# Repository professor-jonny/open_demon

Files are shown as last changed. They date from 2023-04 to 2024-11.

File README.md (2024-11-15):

# Open Demon Project
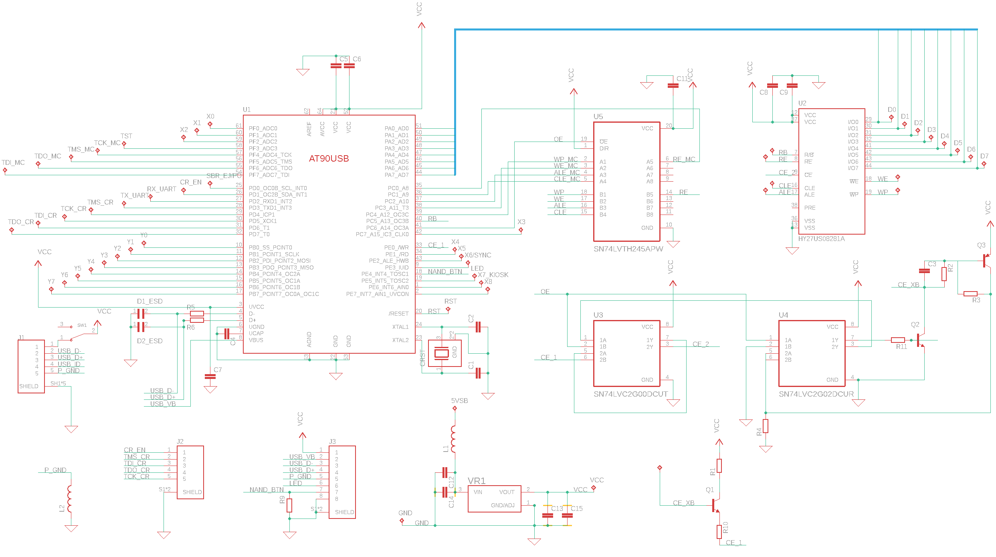
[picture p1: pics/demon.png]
sch

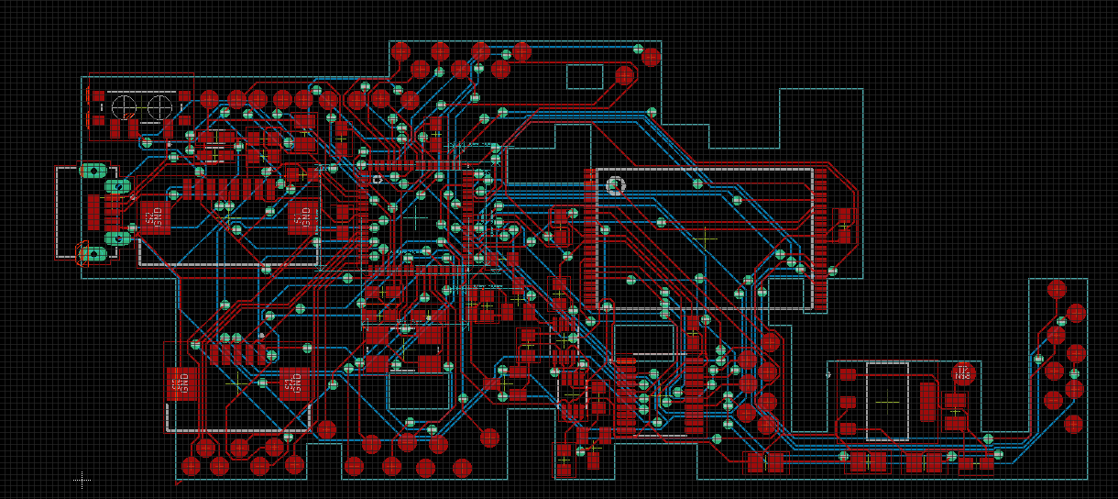
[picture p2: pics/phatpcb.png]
pcb


## Overview:
This project is an open-source recreation of the Team Xecuter Demon, a powerful multi-function NAND device for the Xbox 360. Our goal is to rebuild the firmware, fix existing bugs, and potentially develop new hardware add-ons. We hope this project encourages wider community involvement.

## Demon background:
Released in February 2012 alongside a J-Runner update, the Demon offered an all-in-one solution for NAND programming. While initially successful, it was perhaps over-hyped and ultimately didn't achieve the same market penetration as other Team Xecuter devices. The rise of stealth services further diminished its relevance, and the lack of promised add-on hardware hampered its potential. Numerous planned add-ons never saw a public release due to Team Xecuter's internal challenges. Following financial and legal difficulties, ownership transitioned from K3 to Max.

The Demon provides access to the console's UART for direct interaction, along with extensive onboard I/O capable of supporting a separate 8-bit bus. Additional I/O pins are available for bit-banging SPI, I2C, or other protocols. Although Team Xecuter announced Android and iOS remote control apps in July 2012, these were never released. Similarly, LCD support was explored, with prototypes circulated among developers, but only the NAND switching plugin, Switch!, was officially launched.

## Project Background:
Inspired by discussions with fellow enthusiasts and analysis of the Xbox 360 ODE cracking process, this project began with recreating the Demon's schematics. Access to images of a pre-release slim PCB aided in verification.

Understanding the hardware, components, and design is crucial for reverse engineering. One undocumented aspect is controlling the Demon's hardware and I/O from the console. We aim to document the I/O addressing scheme (if implemented) and investigate the potential for a UART control API. A PC-based USB control API already exists. Third-party add-ons could leverage the Demon's I/O, potentially enabling features like an integrated LCD display.

## Theory of operation:
The Demon's NAND interface largely mirrors the console's onboard NAND, using a tri-state bus transceiver to isolate the microcontroller from the NAND control logic. Control appears to rely on the CE and RB signals, with other control lines interrupted by the transceiver. Logic in U3 prevents simultaneous driving of both CE pins. C3 likely introduces timing delays for CE switching to the Demon's NAND via NOR gates in U4. This, combined with RB, likely determines chip readiness before OE activates, hijacking CE to enable the Demon's NAND. OE also enables the tri-state transceiver and Demon's NAND CE logic when the motherboard's CE is high.

The design seemingly intercepts NAND control between read/write cycles, asserting and locking control while the chip is busy. Analyzing microcontroller-to-NAND communication is necessary for confirmation, but this theory appears plausible.

## Challenges:
The AT90USB microcontroller's bootloader employs custom encryption (believed to be RSA-2048), posing significant challenges. Existing Team Xecuter firmware is unanalyzable, current devices require a bootloader update for compatibility, and a new bootloader would break existing firmware support. Developing new firmware for the current bootloader is blocked by signature checks.

Project advancement hinges on recovering the bootloader or its RSA key. Collaboration with experienced individuals is sought. Donations are welcome to support this effort. While various options have been considered, we remain open to suggestions. Contact is being attempted with the original Team Xecuter developer. Interest exists in manufacturing the device if the bootloader is recovered. Due to on-the-fly firmware unpacking, direct firmware analysis is infeasible. A brown-out reset glitch or physical access is likely required for bootloader recovery. Cracking the RSA key is computationally infeasible.

For this project to go forward I would like to recover the bootloader or at least the RSA key by attacking the microcontroller if any one has experience with this or would be willing to try this it would be awesome if you would contact me.
I don't fancy dropping $1400usd to a chineese firm to do this I would rather give this to a fellow Xbox or scene hacker as this is beyond my skill and a very special area.
I already have a few buddies who would be willing to donate to the cause, So far I have resisted going down the route of croud sourcing the project as realistically I don't think niche projects like this work well on that platform and i'd like to aviod the disapointment for everyone when it fails.
You are welcome to donate to the cause if you wish id love a failed demon hardware so i can fully recreate PCB's.

I'd like to keep it all open source if possible, or it close it for a time to make hardware to recoup costs if we were to fund bootloader recovery there is a whole lot of options I have not explored here and I'm open to suggestions.

I have atempted to contact the original Team Xecuter dev involved with the design and programming of the demon project but have had no luck in getting a reply sadly so it is what it is.

I already have people intrested in manufacturing the device if we do manage to progress futher and recover the bootloader there is intrest to recreate them.

The demon seems to unpack the firmware on the fly and write it to the onbord flash so there is no attack vector there and we would need to preform brown out reset glitch or physical access to recover the bootloader for reverse engineering to get the RSA key.

RSA is currently secure and would take a supercomputer decades to crack the firmware update key embeded within the bootloader.

## Project Outline/ Future Plans:
The future plan is to recrate the 
The primary goal is an open-source Demon recreation, initially compatible with existing hardware. A hardware revision is likely due to component discontinuation. A more ambitious objective involves a new FPGA-based device with a microcontroller. This would enable on-the-fly NAND image creation, kernel patching, and a console configuration app. A shared memory window could facilitate console-microcontroller communication for RAM offloading, code relocation, and coprocessing.

Eaton's testing indicates a NAND bus speed of approximately 1.4 Mbps, suitable for low-bandwidth operations. The impact of using faster media is unknown. This advanced design requires skilled FPGA/CPLD developers. More information is available on 

Eaton's blog:
[eaton works](https://eaton-works.com/2023/01/09/how-microsoft-attempted-to-make-the-xbox-360-dashboard-load-faster/)

The schematics were designed using Eagle:
[Autodesk Eagle]( https://www.autodesk.com/products/eagle/free-download)

## Licensing
This project is open-source. Hardware and schematics are licensed under the [CERN OHL v.2.0.](https://ohwr.org/cernohl).

Donations are welcome to support XBMC4XBOX, Team Resurgent, or other Xbox resources.

[Teamresurgent donate]( https://www.patreon.com/teamresurgent)
[xbmc4xbox donate](https://www.xbmc4xbox.org.uk/donate/)

## Disclaimer
This project is a work in progress and may contain inaccuracies. Feedback and corrections are welcome. Development is ongoing, and Gerber files for all Demon variants will be released eventually. A preliminary Phat PCB design is available.
This project is by no meany complete or possibly accurate it is my own account of insight may be incorect, and I'm open to suggestions and correctons.

## Acknowledgements
We thank Coz, Goobycorp, and Eaton for their invaluable contributions.

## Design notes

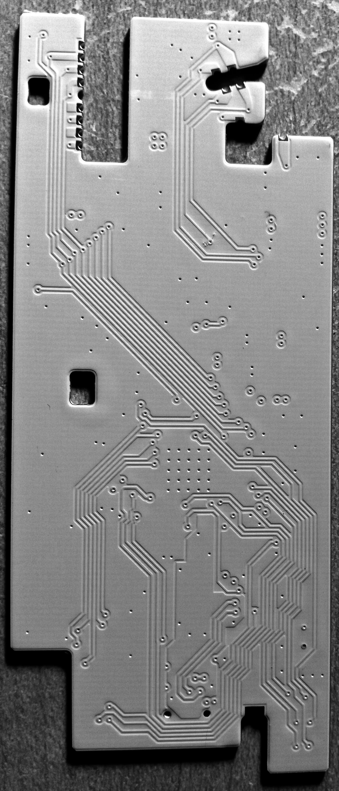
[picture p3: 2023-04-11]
pics/slim_proto_bottom.jpg

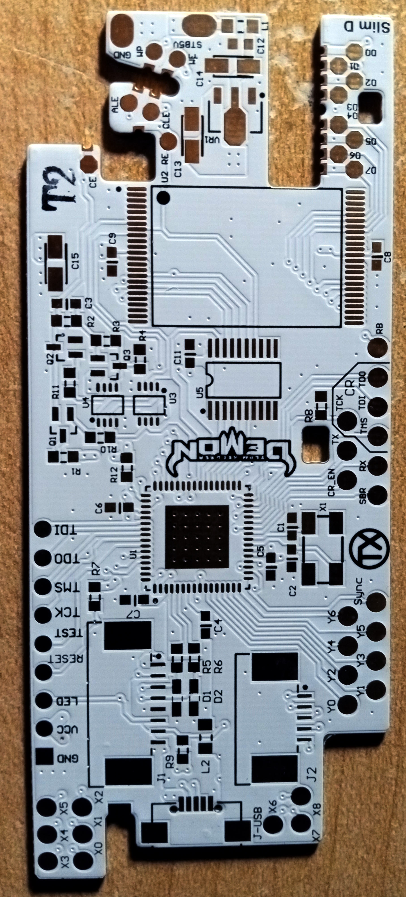
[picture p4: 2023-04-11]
pics/slim_proto_.jpg

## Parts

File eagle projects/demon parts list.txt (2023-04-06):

Partlist

Exported from demon.sch at 27/03/2023 12:23 pm

EAGLE Version 9.6.2 Copyright (c) 1988-2020 Autodesk, Inc.

Assembly variant: 

Part      Value               Device               Package                  Library                   Sheet

5VSB      TPTP20R             TPTP20R              TP20R                    testpad                   1
ALE1      TPTP15R             TPTP15R              TP15R                    testpad                   1
C1        18pf                C-EUC0603            C0603                    rcl                       1
C2        18pf                C-EUC0603            C0603                    rcl                       1
C3        47pf                C-EUC0603            C0603                    rcl                       1
C4        1uf                 C-EUC0603            C0603                    rcl                       1
C5        .1uf                C-EUC0603            C0603                    rcl                       1
C6        .1uf                C-EUC0603            C0603                    rcl                       1
C7        .1uf                C-EUC0603            C0603                    rcl                       1
C8        .1uf                C-EUC0603            C0603                    rcl                       1
C9        .1uf                C-EUC0603            C0603                    rcl                       1
C11       1uf                 C-EUC0603            C0603                    rcl                       1
C12       .1uf                C-EUC0603            C0603                    rcl                       1
C13       2.2uf tant          CC2012               C2012                    eagle-ltspice             1
C14       1uf tant            CC2012               C2012                    eagle-ltspice             1
C15       10uf Tant           CC2012               C2012                    eagle-ltspice             1
CE        TPTP15R             TPTP15R              TP15R                    testpad                   1
CLE1      TPTP15R             TPTP15R              TP15R                    testpad                   1
CRST      ABMM2-8.000MHZ-E2-T ABMM2-8.000MHZ-E2-T  XTAL_ABMM2-8.000MHZ-E2-T ABMM2-8.000MHZ-E2-T       1
CR_EN     TPTP15R             TPTP15R              TP15R                    testpad                   1
D0        TPTP15R             TPTP15R              TP15R                    testpad                   1
D1        TPTP15R             TPTP15R              TP15R                    testpad                   1
D1_ESD    PGB1010603          PGB1010603           ESD_PGB1010603MR         PGB1010603                1
D2        TPTP15R             TPTP15R              TP15R                    testpad                   1
D2_ESD    PGB1010603          PGB1010603           ESD_PGB1010603MR         PGB1010603                1
D3        TPTP15R             TPTP15R              TP15R                    testpad                   1
D4        TPTP15R             TPTP15R              TP15R                    testpad                   1
D5        TPTP15R             TPTP15R              TP15R                    testpad                   1
D6        TPTP15R             TPTP15R              TP15R                    testpad                   1
D7        TPTP15R             TPTP15R              TP15R                    testpad                   1
GND       TPTP15R             TPTP15R              TP15R                    testpad                   1
J1        UJ2-MIBH2-4-SMT     UJ2-MIBH2-4-SMT      CUI_UJ2-MIBH2-4-SMT      UJ2-MIBH2-4-SMT           1
J2        FFC3B07-05-T        FFC3B07-05-T         GCT_FFC3B07-05-T         FFC3B07-05-T              1
J3        FFC3B07-08-T        FFC3B07-08-T         GCT_FFC3B07-08-T         FFC3B07-08-T              1
L1        LQW2BAS6N8J00L      LQW2BAS6N8J00L       INDC2015X152N            LQW2BAS6N8J00L            1
L2        LQW2BAS6N8J00L      LQW2BAS6N8J00L       INDC2015X152N            LQW2BAS6N8J00L            1
LED       TPTP15R             TPTP15R              TP15R                    testpad                   1
Q1        BC846               BC846                SOT23                    transistor                1
Q2        BC846               BC846                SOT23                    transistor                1
Q3        bc856               BC856A-PNP-SOT23-BEC SOT23-BEC                transistor                1
R1        22R 5%              R-EU_R0603           R0603                    resistor                  1
R2        470R 5%             R-EU_R0603           R0603                    resistor                  1
R3        2k7R 5%             R-EU_R0603           R0603                    resistor                  1
R4        330R 5%             R-EU_R0603           R0603                    resistor                  1
R5        22r 5%              R-EU_R0603           R0603                    resistor                  1
R6        22R 5%              R-EU_R0603           R0603                    resistor                  1
R9        10kR 5%             R-EU_R0603           R0603                    resistor                  1
R10       68R 5%              R-EU_R0603           R0603                    resistor                  1
R11       680R 5%             R-EU_R0603           R0603                    resistor                  1
RB1       TPTP15R             TPTP15R              TP15R                    testpad                   1
RE        TPTP15R             TPTP15R              TP15R                    testpad                   1
RST       TPTP15R             TPTP15R              TP15R                    testpad                   1
RX_UART   TPTP15R             TPTP15R              TP15R                    testpad                   1
SBR_EJ/PO TPTP15R             TPTP15R              TP15R                    testpad                   1
SW1       EG1215AA            EG1215AA             SW_EG1215AA              EG1215AA                  1
TCK_CR    TPTP15R             TPTP15R              TP15R                    testpad                   1
TCK_MC    TPTP15R             TPTP15R              TP15R                    testpad                   1
TDI_CR    TPTP15R             TPTP15R              TP15R                    testpad                   1
TDI_MC    TPTP15R             TPTP15R              TP15R                    testpad                   1
TDO_CR    TPTP15R             TPTP15R              TP15R                    testpad                   1
TDO_MC    TPTP15R             TPTP15R              TP15R                    testpad                   1
TMS_CR    TPTP15R             TPTP15R              TP15R                    testpad                   1
TMS_MC    TPTP15R             TPTP15R              TP15R                    testpad                   1
TST       TPTP15R             TPTP15R              TP15R                    testpad                   1
TX_UART   TPTP15R             TPTP15R              TP15R                    testpad                   1
U1                            AT90USB-QFN          QFN64                    controller-micro_atmel_jd 1
U2        HY27US08281A        HY27US08281A         TSOP48                   memory-hynix              1
U3        SN74LVC2G00DCUT     SN74LVC2G00DCUT      SOP50P310X90-8N          SN74LVC2G00DCUT           1
U4        SN74LVC2G02DCUR     SN74LVC2G02DCUR      SOP50P310X90-8N          SN74LVC2G02DCUR           1
U5        SN74LVTH245APW      SN74LVTH245APW       SOP65P640X120-20N        SN74LVTH245APW            1
VCC       TPTP15R             TPTP15R              TP15R                    testpad                   1
VR1       AMS1117-3.3         AMS1117-3.3          SOT229P700X180-4N        AMS1117-3.3               1
WE1       TPTP15R             TPTP15R              TP15R                    testpad                   1
WP1       TPTP15R             TPTP15R              TP15R                    testpad                   1
X0        TPTP15R             TPTP15R              TP15R                    testpad                   1
X1        TPTP15R             TPTP15R              TP15R                    testpad                   1
X2        TPTP15R             TPTP15R              TP15R                    testpad                   1
X3        TPTP15R             TPTP15R              TP15R                    testpad                   1
X4        TPTP15R             TPTP15R              TP15R                    testpad                   1
X5        TPTP15R             TPTP15R              TP15R                    testpad                   1
X6/SYNC   TPTP15R             TPTP15R              TP15R                    testpad                   1
X7_KIOSK  TPTP15R             TPTP15R              TP15R                    testpad                   1
X8        TPTP15R             TPTP15R              TP15R                    testpad                   1
Y0        TPTP15R             TPTP15R              TP15R                    testpad                   1
Y1        TPTP15R             TPTP15R              TP15R                    testpad                   1
Y2        TPTP15R             TPTP15R              TP15R                    testpad                   1
Y3        TPTP15R             TPTP15R              TP15R                    testpad                   1
Y4        TPTP15R             TPTP15R              TP15R                    testpad                   1
Y5        TPTP15R             TPTP15R              TP15R                    testpad                   1
Y6        TPTP15R             TPTP15R              TP15R                    testpad                   1
Y7        TPTP15R             TPTP15R              TP15R                    testpad                   1

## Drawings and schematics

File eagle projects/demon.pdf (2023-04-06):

SN74LVTH245APW | VCC | VCC VCC
SN74LVC2G02DCUR VCC | VCC VCC | VCC VCC VCC

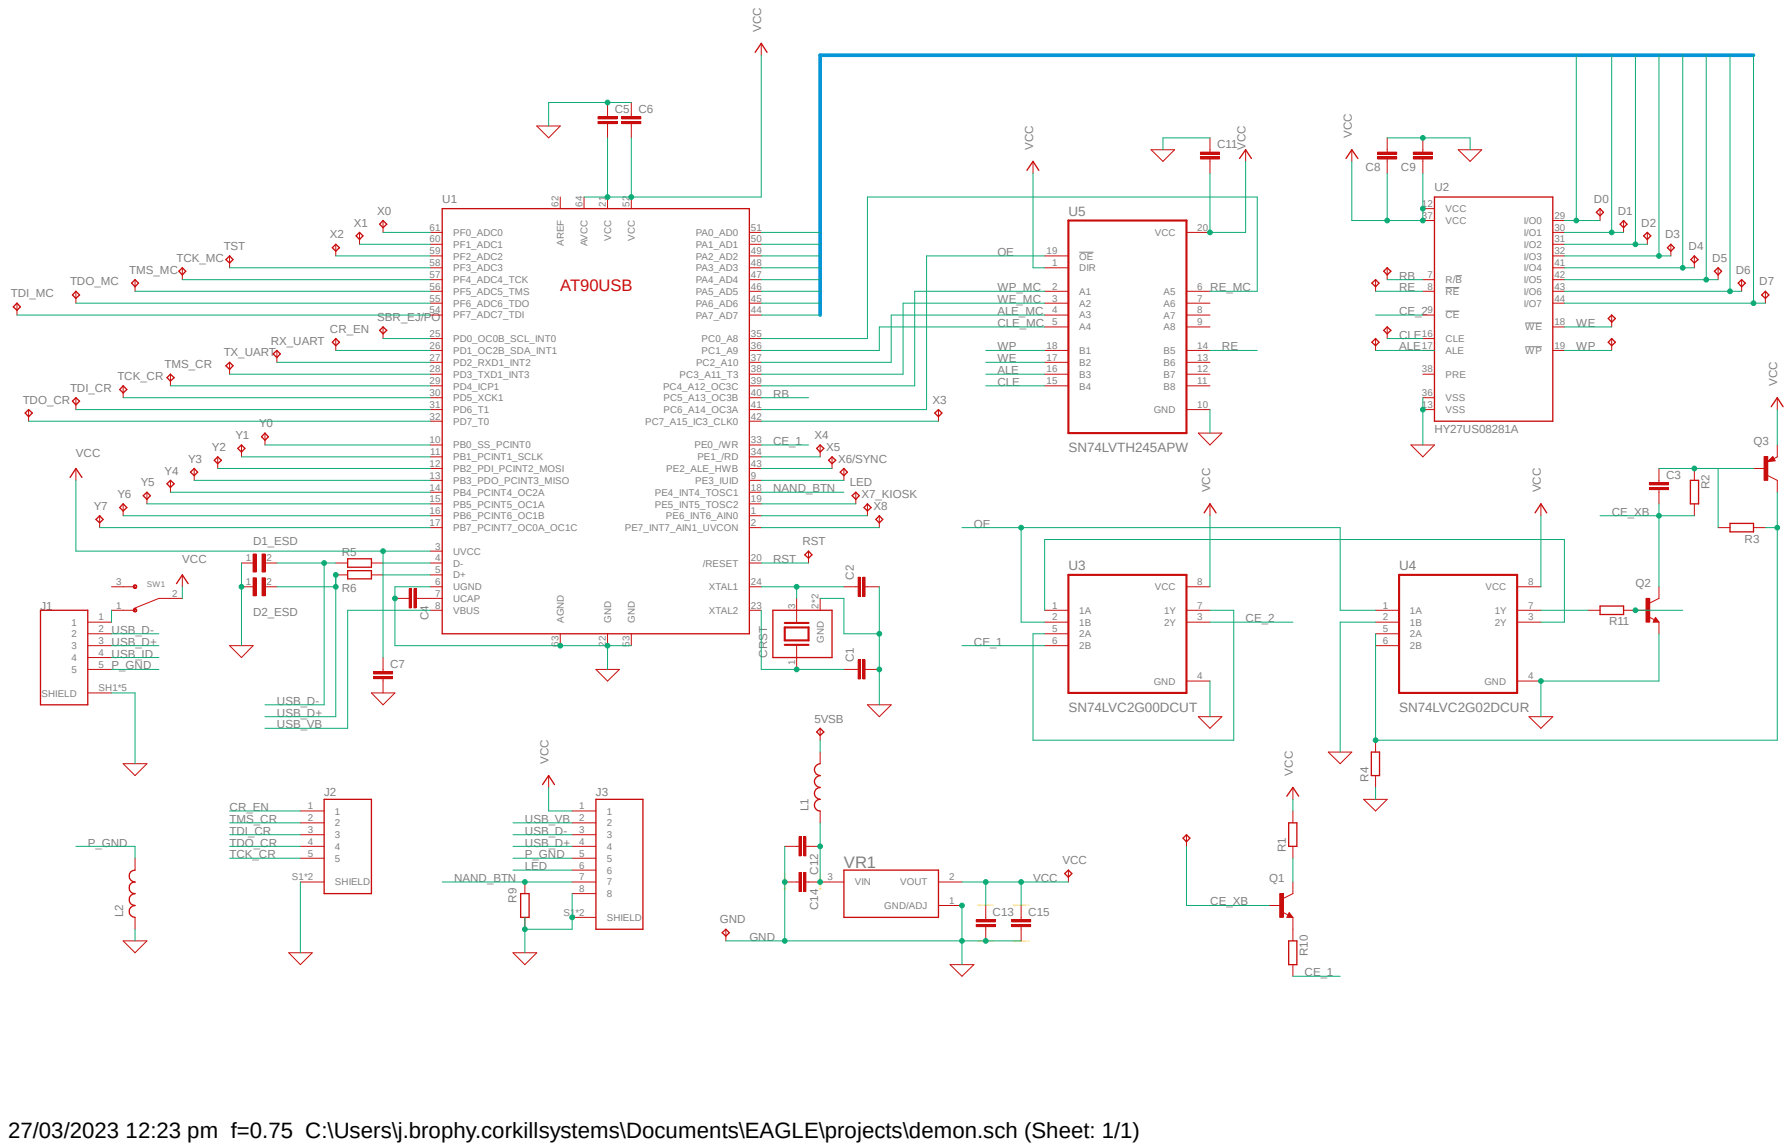
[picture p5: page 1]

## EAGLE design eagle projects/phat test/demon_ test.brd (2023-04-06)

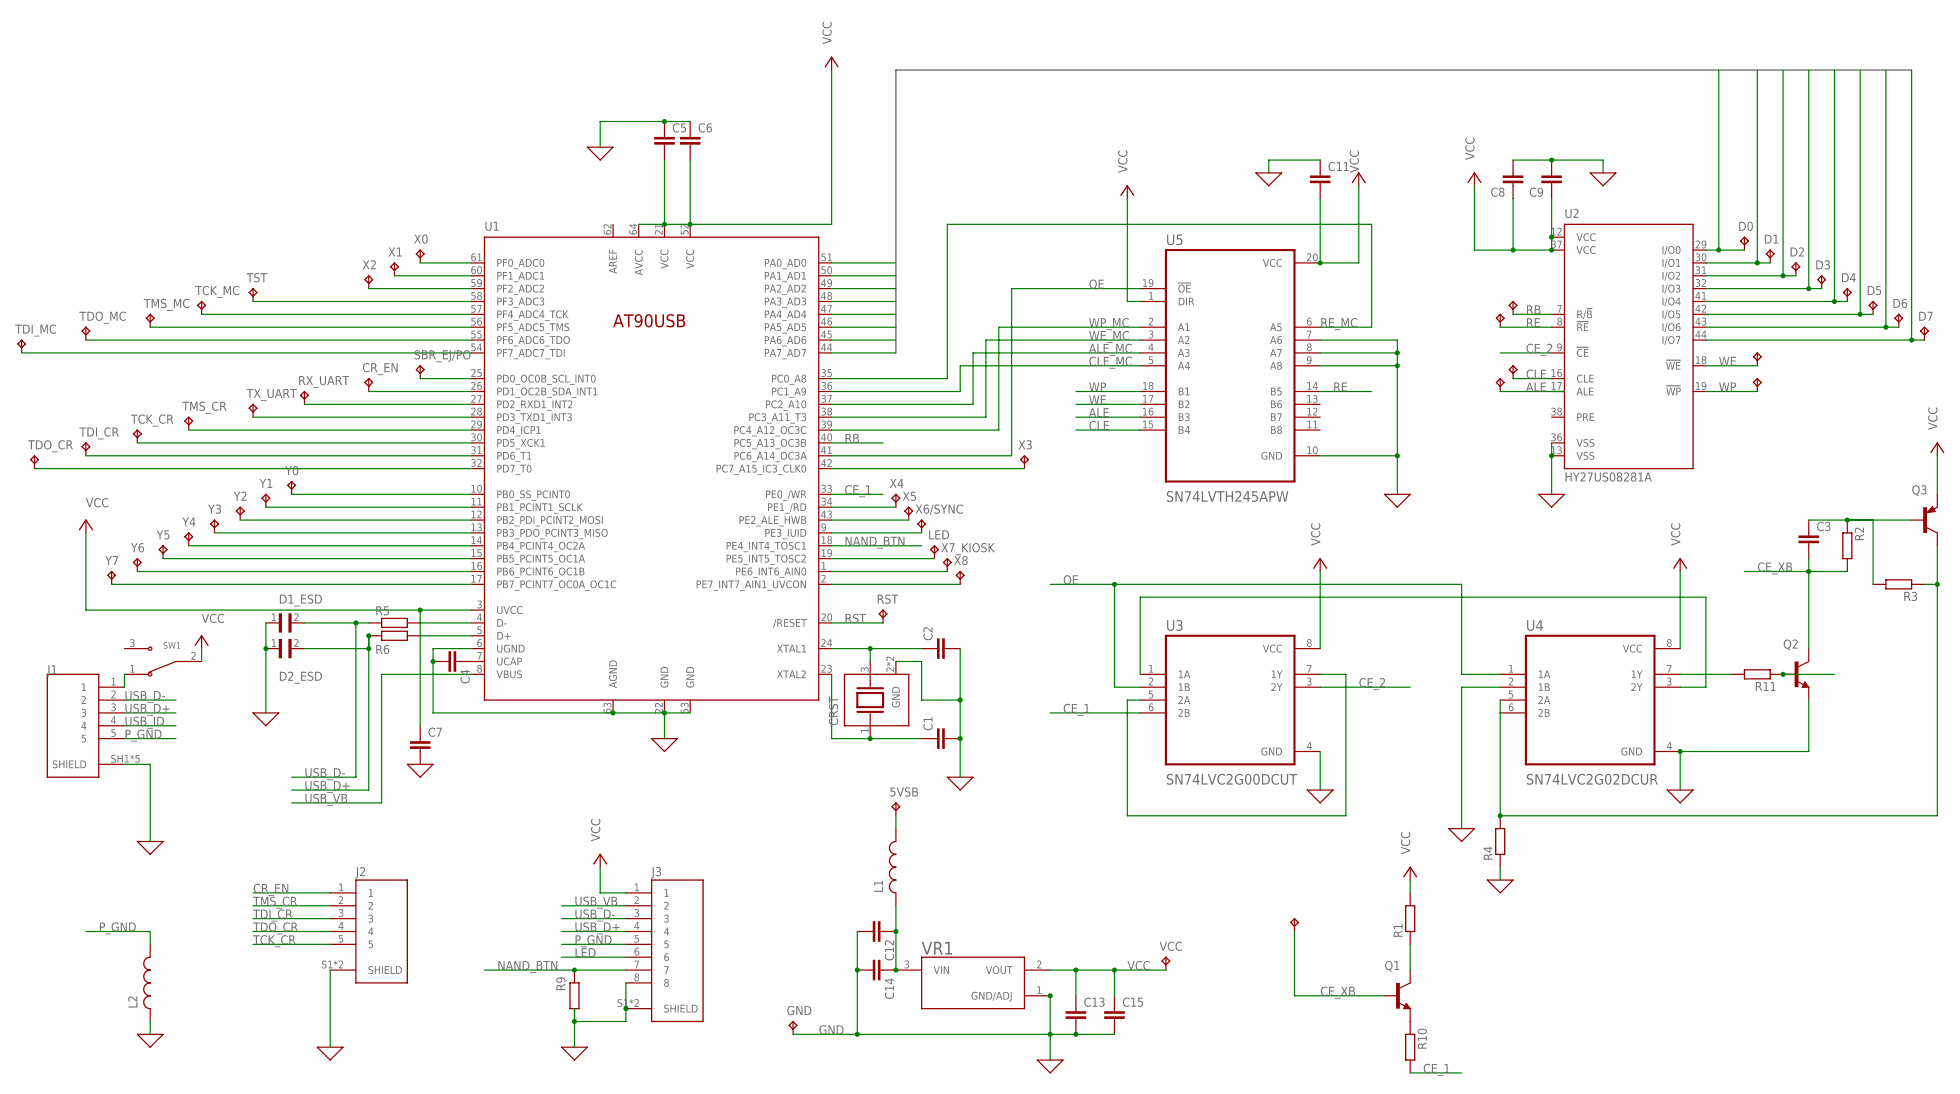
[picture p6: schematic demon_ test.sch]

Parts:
5VSB: TPTP20R; TP20R
ALE1: TPTP15R; TP15R
C1, C2: 18pf; C0603
C3: 47pf; C0603
C4, C11: 1uf; C0603
C5, C6, C7, C8, C9, C12: .1uf; C0603
C13: 2.2uf tant; C2012
C14: 1uf tant; C2012
C15: 10uf Tant; C2012
CE: TPTP15R; TP15R
CLE1: TPTP15R; TP15R
CRST: ABMM2-8.000MHZ-E2-T; XTAL_ABMM2-8.000MHZ-E2-T
CR_EN: TPTP15R; TP15R
D0, D1, D2, D3, D4, D5, D6, D7: TPTP15R; TP15R
D1_ESD, D2_ESD: PGB1010603; ESD_PGB1010603MR
GND: TPTP15R; TP15R
J1: UJ2-MIBH2-4-SMT; CUI_UJ2-MIBH2-4-SMT
J2: FFC3B07-05-T; GCT_FFC3B07-05-T
J3: FFC3B07-08-T; GCT_FFC3B07-08-T
L1, L2: LQW2BAS6N8J00L; INDC2015X152N
LED: TPTP15R; TP15R
Q1, Q2: BC846; SOT23
Q3: bc856; SOT23-BEC
R1, R6: 22R 5%; R0603
R2: 470R 5%; R0603
R3: 2k7R 5%; R0603
R4: 330R 5%; R0603
R5: 22r 5%; R0603
R9: 10kR 5%; R0603
R10: 68R 5%; R0603
R11: 680R 5%; R0603
RB1: TPTP15R; TP15R
RE: TPTP15R; TP15R
RST: TPTP15R; TP15R
RX_UART: TPTP15R; TP15R
SBR_EJ/PO: TPTP15R; TP15R
SW1: EG1215AA; SW_EG1215AA
TCK_CR: TPTP15R; TP15R
TCK_MC: TPTP15R; TP15R
TDI_CR: TPTP15R; TP15R
TDI_MC: TPTP15R; TP15R
TDO_CR: TPTP15R; TP15R
TDO_MC: TPTP15R; TP15R
TMS_CR: TPTP15R; TP15R
TMS_MC: TPTP15R; TP15R
TST: TPTP15R; TP15R
TX_UART: TPTP15R; TP15R
U1: AT90USB-QFN; QFN64
U2: HY27US08281A; TSOP48
U3: SN74LVC2G00DCUT; SOP50P310X90-8N
U4: SN74LVC2G02DCUR; SOP50P310X90-8N
U5: SN74LVTH245APW; SOP65P640X120-20N
VCC: TPTP15R; TP15R
VR1: AMS1117-3.3; SOT229P700X180-4N
WE1: TPTP15R; TP15R
WP1: TPTP15R; TP15R
X0, X1, X2, X3, X4, X5, X6/SYNC, X7_KIOSK, X8: TPTP15R; TP15R
Y0, Y1, Y2, Y3, Y4, Y5, Y6, Y7: TPTP15R; TP15R

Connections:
0: C7.2, U5.7 (A6), U5.8 (A7), U5.9 (A8), U5.10 (GND)
ALE: ALE1.TP, U2.17 (ALE), U5.16 (B3)
ALE_MC: U1.37 (PC2_A10), U5.4 (A3)
AREF: U1.62 (AREF)
CE_1: R10.2, U1.33 (PE0_/WR), U3.6 (2B)
CE_2: U2.9 (!CE), U3.3 (2Y)
CE_XB: C3.2, CE.TP, Q1.1 (B), Q2.3 (C), R2.2
CLE: CLE1.TP, U2.16 (CLE), U5.15 (B4)
CLE_MC: U1.36 (PC1_A9), U5.5 (A4)
CR_EN: CR_EN.TP, J2.1, U1.26 (PD1_OC2B_SDA_INT1)
D0: D0.TP, U1.51 (PA0_AD0), U2.29 (I/O0)
D1: D1.TP, U1.50 (PA1_AD1), U2.30 (I/O1)
D2: D2.TP, U1.49 (PA2_AD2), U2.31 (I/O2)
D3: D3.TP, U1.48 (PA3_AD3), U2.32 (I/O3)
D4: D4.TP, U1.47 (PA4_AD4), U2.41 (I/O4)
D5: D5.TP, U1.46 (PA5_AD5), U2.42 (I/O5)
D6: D6.TP, U1.45 (PA6_AD6), U2.43 (I/O6)
D7: D7.TP, U1.44 (PA7_AD7), U2.44 (I/O7)
F_5VSB: C12.1, C14.1, L1.1, VR1.3 (VIN)
GND: C1.2, C2.2, C4.2, C5.1, C6.1, C8.2, C9.2, C11.1, C12.2, C13.2, C14.2, C15.2, CRST.2 (GND), CRST.4 (GND), D1_ESD.1, D2_ESD.1, GND.TP, J1.SH1 (SHIELD), J1.SH2 (SHIELD), J1.SH3 (SHIELD), J1.SH4 (SHIELD), J1.SH5 (SHIELD), J2.S1 (SHIELD), J2.S2 (SHIELD), J3.8, J3.S1 (SHIELD), J3.S2 (SHIELD), L2.1, Q2.2 (E), R4.1, R9.2, U1.6 (UGND), U1.22 (GND), U1.53 (GND), U1.63 (AGND), U2.13 (VSS), U2.36 (VSS), U3.4 (GND), U4.2 (1B), U4.4 (GND), VR1.1 (GND/ADJ)
LED: J3.6, LED.TP, U1.19 (PE5_INT5_TOSC2)
unnamed: R5.2, U1.4 (D-)
unnamed: C3.1, Q3.B, R2.1, R3.2
unnamed: C4.1, U1.7 (UCAP)
unnamed: R6.2, U1.5 (D+)
unnamed: Q1.3 (C), R1.1
unnamed: Q1.2 (E), R10.1
unnamed: 5VSB.TP, L1.2
unnamed: U3.5 (2A), U3.7 (1Y)
unnamed: U3.1 (1A), U4.3 (2Y)
unnamed: R11.2, U4.7 (1Y)
unnamed: Q2.1 (B), R11.1
unnamed: Q3.C, R3.1, R4.2, U4.5 (2A), U4.6 (2B)
unnamed: J1.1, SW1.1
NAND_BTN: J3.7, R9.1, U1.18 (PE4_INT4_TOSC1)
OE: U1.41 (PC6_A14_OC3A), U3.2 (1B), U4.1 (1A), U5.19 (!OE)
P_GND: J1.5, J3.5, L2.2
RB: RB1.TP, U1.40 (PC5_A13_OC3B), U2.7 (R/!B)
RE: RE.TP, U2.8 (!RE), U5.14 (B5)
RE_MC: U1.35 (PC0_A8), U5.6 (A5)
RST: RST.TP, U1.20 (/RESET)
RX_UART: RX_UART.TP, U1.27 (PD2_RXD1_INT2)
SBR: SBR_EJ/PO.TP, U1.25 (PD0_OC0B_SCL_INT0)
TCK_CR: J2.5, TCK_CR.TP, U1.30 (PD5_XCK1)
TCK_MC: TCK_MC.TP, U1.57 (PF4_ADC4_TCK)
TD0_MC: TDO_MC.TP, U1.55 (PF6_ADC6_TDO)
TDI_CR: J2.3, TDI_CR.TP, U1.31 (PD6_T1)
TDI_MC: TDI_MC.TP, U1.54 (PF7_ADC7_TDI)
TDO_CR: J2.4, TDO_CR.TP, U1.32 (PD7_T0)
TMS_CR: J2.2, TMS_CR.TP, U1.29 (PD4_ICP1)
TMS_MC: TMS_MC.TP, U1.56 (PF5_ADC5_TMS)
TST: TST.TP, U1.58 (PF3_ADC3)
TX_UART: TX_UART.TP, U1.28 (PD3_TXD1_INT3)
USB_D+: D2_ESD.2, J1.3, J3.4, R6.1
USB_D-: D1_ESD.2, J1.2, J3.3, R5.1
USB_ID: J1.4
USB_VB: J3.2, U1.8 (VBUS)
VCC: C5.2, C6.2, C7.1, C8.1, C9.1, C11.2, C13.1, C15.1, J3.1, Q3.E, R1.2, SW1.2, U1.3 (UVCC), U1.21 (VCC), U1.52 (VCC), U1.64 (AVCC), U2.12 (VCC), U2.37 (VCC), U3.8 (VCC), U4.8 (VCC), U5.1 (DIR), U5.20 (VCC), VCC.TP, VR1.2 (VOUT)
WE: U2.18 (!WE), U5.17 (B2), WE1.TP
WE_MC: U1.38 (PC3_A11_T3), U5.3 (A2)
WP: U2.19 (!WP), U5.18 (B1), WP1.TP
WP_MC: U1.39 (PC4_A12_OC3C), U5.2 (A1)
X0: U1.61 (PF0_ADC0), X0.TP
X1: U1.60 (PF1_ADC1), X1.TP
X2: U1.59 (PF2_ADC2), X2.TP
X3: U1.42 (PC7_A15_IC3_CLK0), X3.TP
X4: U1.34 (PE1_/RD), X4.TP
X5: U1.43 (PE2_ALE_HWB), X5.TP
X6/SYNC: U1.9 (PE3_IUID), X6/SYNC.TP
X7: U1.1 (PE6_INT6_AIN0), X7_KIOSK.TP
X8: U1.2 (PE7_INT7_AIN1_UVCON), X8.TP
XTAL1: C2.1, CRST.3 (2), U1.24 (XTAL1)
XTAL2: C1.1, CRST.1, U1.23 (XTAL2)
Y0: U1.10 (PB0_SS_PCINT0), Y0.TP
Y1: U1.11 (PB1_PCINT1_SCLK), Y1.TP
Y2: U1.12 (PB2_PDI_PCINT2_MOSI), Y2.TP
Y3: U1.13 (PB3_PDO_PCINT3_MISO), Y3.TP
Y4: U1.14 (PB4_PCINT4_OC2A), Y4.TP
Y5: U1.15 (PB5_PCINT5_OC1A), Y5.TP
Y6: U1.16 (PB6_PCINT6_OC1B), Y6.TP
Y7: U1.17 (PB7_PCINT7_OC0A_OC1C), Y7.TP

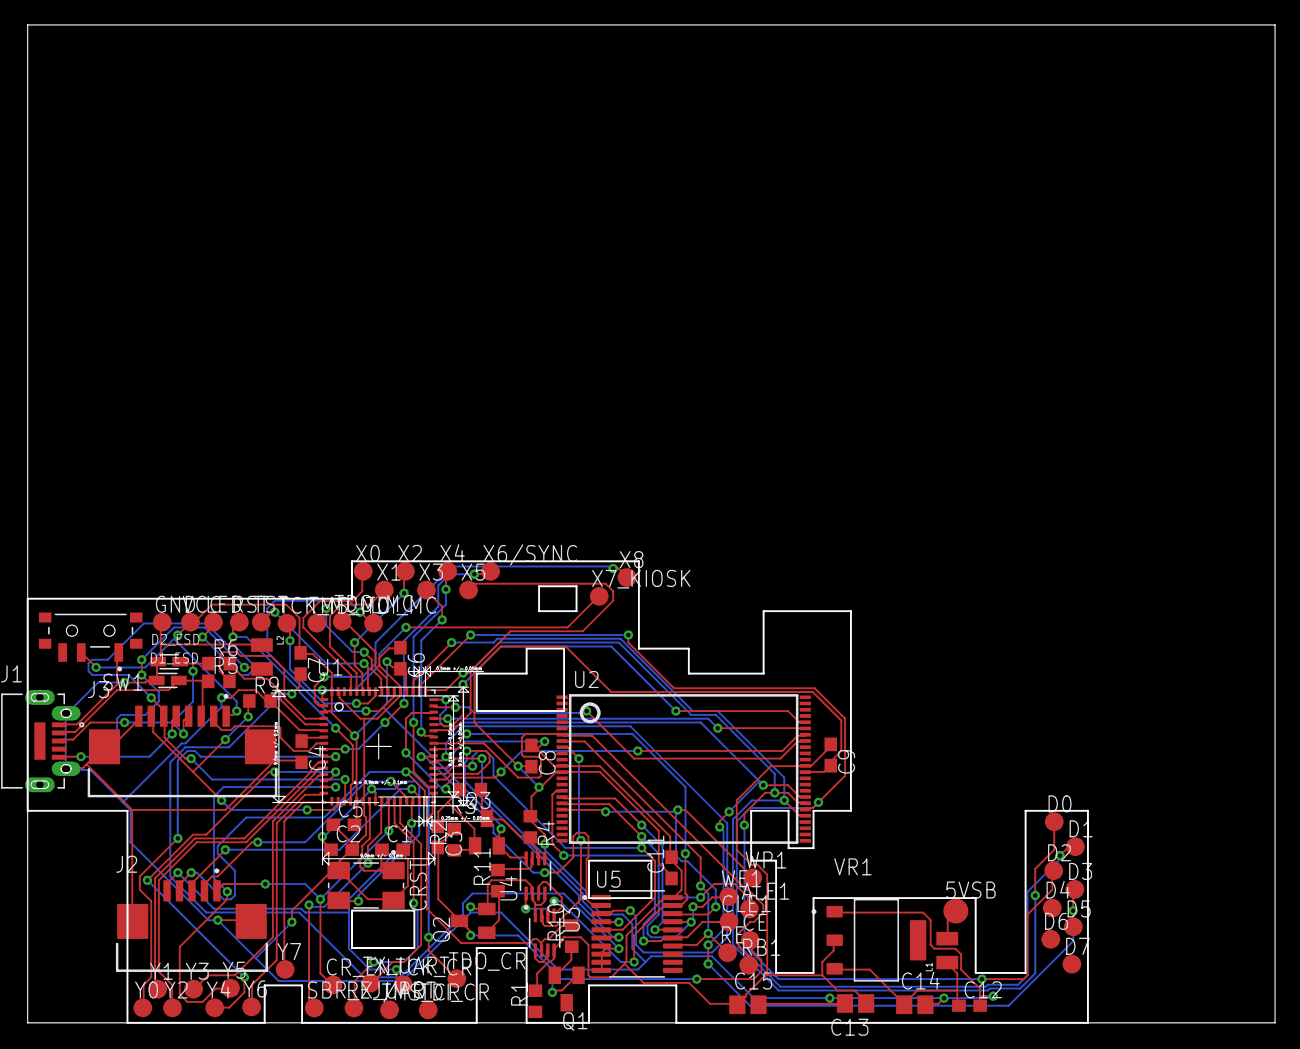
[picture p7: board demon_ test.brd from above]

Board: 2 copper layers, 100.0 x 80.0 mm, 91 parts (0 on the bottom side), 79 nets.

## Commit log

2023-04-06 initial import
    Initial project import
    [demon.brd, demon.sch, demon_ test.brd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]
2024-11-15 Update README.md
    Docs: Rewrote README for improved clarity, grammar, and style. Addressed issues with sentence structure, word choice, and technical explanations.
    README: Comprehensive rewrite focusing on clarity and conciseness. Improved technical descriptions and addressed potential ambiguities. Formalized language and improved overall flow.
    Documentation: Overhauled README to enhance readability for a wider audience. Clarified technical details, corrected grammar and spelling, and adopted a more professional tone.
2024-11-15 Update README.md
    Moved schematic images back to the beginning of the README. They were previously moved, but this placement provides better initial context for the project.
